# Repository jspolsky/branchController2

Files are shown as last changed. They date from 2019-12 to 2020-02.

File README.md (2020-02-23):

branchController
================

The Branch Controller is a small hardware board based on the [Teensy 3.2 development board](https://www.pjrc.com/store/teensy32.html) to allow it to control up to 8 separate pixel-addressible LED strips.

Although it can be used standalone to send its own patterns to the light strips, it really shines when connected, over ethernet, to a network. That allows you to generate the patterns on a computer (say, with a high powered graphics card) and send them to one or more Branch Controllers. In particular you can drive a lot more LEDs than any single controller can drive by using multiple Branch Controllers.

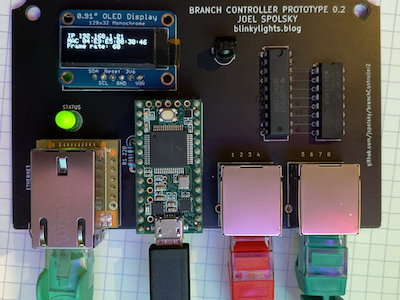
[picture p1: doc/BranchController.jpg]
Branch Controller


It is designed for WS2812b-style LED strips, with a single wire protocol. These are what Adafruit calls "NeoPixels".

Personally I like to use the WS2815 variant which runs on 12 volts and has a backup wire allowing any single pixel to fail. 

Branch Controller does *not* handle APA102c-type strips, which use a two wire protocol consisting of both the signal and a clock.

Features:

* Supports up to 4400 pixels (550 per strip) at a frame rate of 60 Hz, the theoretical limit of the protocol

* Ethernet control. Connects to an ethernet network to receive pixel data over TCP/IP. This allows you to use many branch controllers controlled from a single PC

* 128x32 OLED display for diagnostics and network configuration

* IR sensor allows you to use an IR remote control for basic controls

Basic Operation
---------------

By default branchController assumes you have 8 strips of 550 pixels each. You can operate a single branchController with a 44 button IR remote control like this one:

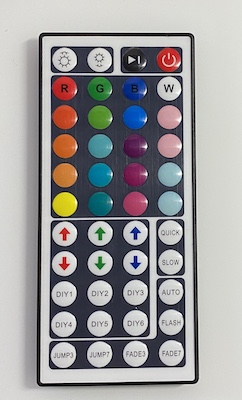
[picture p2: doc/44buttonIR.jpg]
44 button IR remote control


The brightness and color buttons work out of the box so you can use your branch controller to create basic solid colors. 

Use the On/Off button on the remote to turn off the LEDs. When you press OFF, any changes you have made to the state of the branchController is saved to EEPROM so that it will come back in the same state when you power up. *If you don't press off, the state is never saved*.

The DIY1-6 buttons are reserved for internal test patterns and chases. You can edit the code for these to provide something that is a good backup if your PC or network fails.

DIY1 shows a test pattern where the first pixel is brown on the first strip, the first two pixels are brown on the second strip, etc. This is useful for making sure you have the 8 strips hooked up in the right order.

Network Operation
-----------------

You can connect your branchController to a LAN using the built-in ethernet port and control it from any kind of computer that speaks TCP/IP.

When branchController starts up, it will look for a DHCP server and try to get an IP address and network configuration. If that works it will show you the IP address on the screen.

Every branch controller has a unique MAC address which will never change, so you can configure your DHCP server to always hand out the same IP address to the same branch controller, which makes it easier to sort out multiple branch controllers.

If you would like to use a static IP address:

* Start up the branch controller once using DHCP
* Connect to the web server running at the IP address that you see on the OLED display
* Check the "static IP" box and enter the IP address you want to use. Click submit
* Restart the branch controller. From now on it will use your static IP address.

Web-based Hardware Configuration
--------------------------------

If you don't like the default configuration, you can use a web browser to connect to your
branchController and modify some things:

* the maximum power that LEDs will be allowed to consume (in milliwatts). If the total power budget is exceeded, all LEDs will be dimmed equally.
* the RGB order in your LED strips (some strips expect RGB, others expect GRB). Use the "red", "green", and "blue" buttons to diagnose incorrect RGB order.
* the color correction you want applied to all output, as a six digit hex RGB value
* the color temperature you want applied to all output, as a six digit hex RGB value
* the overall brightness of the LEDs, on a scale from 0 (off) to 255 (full). This can
  also be adjusted with an IR remote
* whether to use a static IP address 

See http://fastled.io/docs/3.1/group___color_enums.html for options for color correction and 
color temperature.

Open Pixel Control
------------------

If branchController successfully gets on the Internet, it will listen for TCP connections on port 7890, where it will receive data sent to it using the Open Pixel Control format, documented [here](http://openpixelcontrol.org/). You can use Christopher Schardt's app [L.E.D. Lab](https://apps.apple.com/us/app/l-e-d-lab/id832042156) for iPhone or iPad to send cool animations -- all you need to do is set up the controller as if it were a FadeCandy controller.

We use TCP and not UDP for Open Pixel Control. The w5500 ethernet chip used in this design has a tiny buffer and will lose UDP packets if they are sent too fast. TCP solves this problem.

About the project
-----------------

This code was built using PlatformIO, an open source platform for embedded development which is a zillion times better than using the Arduino IDE. You will still need Teensyduino to flash the Teensy. For more about the research behind this project, follow my blog, [BlinkyLights](https://blinkylights.blog/).

Want to build one?
-------------------
* The gerber directory has gerber and drill files so you can order PCBs.
* This [BOM](https://octopart.com/bom-tool/tv6ZDeDl) lists the parts you need.
* The PCB is designed to be mounted in a Polycase SK-16-03 if you want a weatherproof enclosure

Next Up
-------

Recently implemented:
- [X] Static IP address
- [X] Faster brightness adjust

These features are planned REAL SOON NOW:
- [ ] Improve power limiting feature by showing stats on display for diagnosis
- [ ] "Count Pixels" mode
- [ ] Investigate temporal dithering - it's not really happening. 
- [ ] Internet cable disconnected / reconnected
- [ ] Better built-in (DIY1-6) displays maybe
- [ ] Support remote control Play/Pause button for internal DIY1-6 displays
- [ ] Either implement gamma correction or stop pretending

Ideas for future improvements:
- [ ] New hardware design with ESP32 and logic shifters to handle way more LEDs
- [ ] TouchDesigner support
- [ ] DMX/ArtNet bridge mode
- [ ] Multicast DNS (mDNS) and service discovery (DNS-SD)
      try https://github.com/TrippyLighting/EthernetBonjour

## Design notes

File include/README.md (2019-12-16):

Hey! I hate C++ objects. So I don't really use them that much. We use namespaces instead.

Each "module" defines one namespace and consists of a .h file and a .cpp file. The average module implements both setup() and void() which do the usual Arduino things.

Global constants (like pin assignments) go in BranchController.h. 
Specific settings to this module go in ModuleName.h.

ModuleName.h
---

```
// Description of the module is 
// in the .h file

#pragma once

namespace ModuleName {
    void setup(void);
    void loop(void); 
}

```

ModuleName.cpp
---

```
#include <Arduino.h>
#include <BranchController.h>
#include <ModuleName.h>

namespace ModuleName {

    void setup(void)
    {

    }

    void loop(void)
    {

    }

}
```

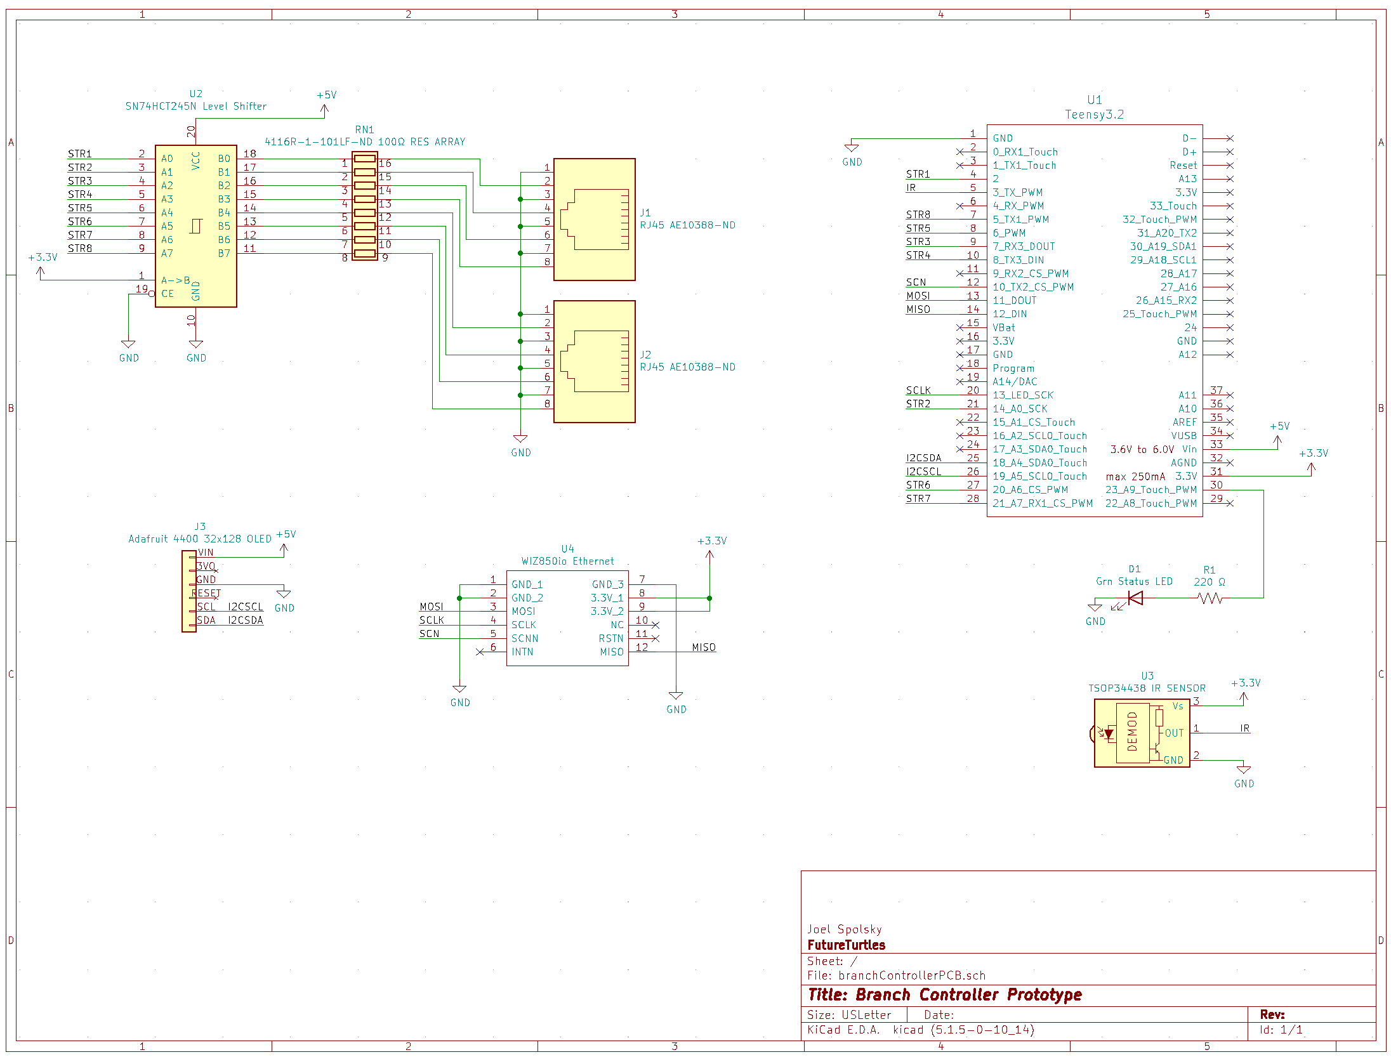
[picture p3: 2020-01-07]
kicad/BranchControllerSchematic.png

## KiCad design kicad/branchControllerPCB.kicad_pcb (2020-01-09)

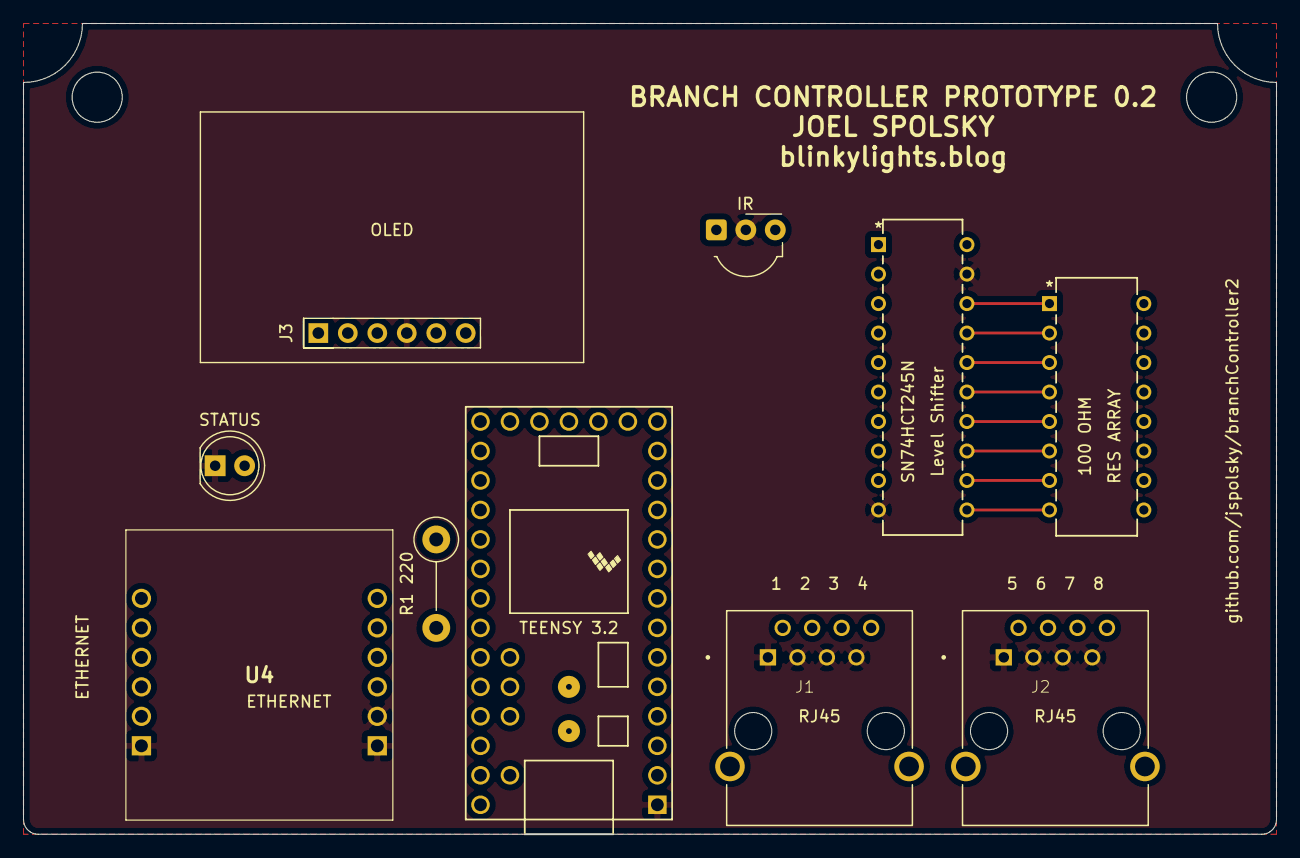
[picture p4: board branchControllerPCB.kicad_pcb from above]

Board: 4 copper layers, 107.9 x 69.9 mm, 10 parts (0 on the bottom side), 36 nets.

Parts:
100 OHM: RES ARRAY; 4116R-1-101LF
IR: TSOP34438 IR SENSOR; Vishay_MOLD-3Pin
J1, J2: RJ45 AE10388-ND; ASSMANN_A-2004-1-4-LP-N-R
J3: Adafruit 4400 32x128 OLED; AdaFruit4400LED
R1 220: 220 Ω; R_Axial_DIN0411_L9.9mm_D3.6mm_P7.62mm_Vertical
SN74HCT245N: Level Shifter; SN74HCT245N
STATUS: Grn Status LED; LED_D5.0mm
TEENSY 3.2: Teensy3.2; Teensy30_31_32_LC
U4: WIZ850io Ethernet; WIZ850io

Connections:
+3V3: IR.3, SN74HCT245N.1, TEENSY 3.2.31, U4.8, U4.9
+5V: J3.VIN, SN74HCT245N.20, TEENSY 3.2.33
/I2CSCL: J3.SCL, TEENSY 3.2.26
/I2CSDA: J3.SDA, TEENSY 3.2.25
/IR: IR.1, TEENSY 3.2.5
/MISO: TEENSY 3.2.14, U4.12
/MOSI: TEENSY 3.2.13, U4.3
/SCLK: TEENSY 3.2.20, U4.4
/SCN: TEENSY 3.2.12, U4.5
/STR1: SN74HCT245N.2, TEENSY 3.2.4
/STR2: SN74HCT245N.3, TEENSY 3.2.21
/STR3: SN74HCT245N.4, TEENSY 3.2.9
/STR4: SN74HCT245N.5, TEENSY 3.2.10
/STR5: SN74HCT245N.6, TEENSY 3.2.8
/STR6: SN74HCT245N.7, TEENSY 3.2.27
/STR7: SN74HCT245N.8, TEENSY 3.2.28
/STR8: SN74HCT245N.9, TEENSY 3.2.7
GND: IR.2, J1.1, J1.3, J1.5, J1.7, J2.1, J2.3, J2.5, J2.7, J3.GND, SN74HCT245N.10, SN74HCT245N.19, STATUS.1, TEENSY 3.2.1, U4.1, U4.2, U4.7
unnamed: R1 220.1, STATUS.2
unnamed: 100 OHM.16, J1.2
unnamed: 100 OHM.15, J1.4
unnamed: 100 OHM.14, J1.6
unnamed: 100 OHM.13, J1.8
unnamed: 100 OHM.12, J2.2
unnamed: 100 OHM.11, J2.4
unnamed: 100 OHM.10, J2.6
unnamed: 100 OHM.9, J2.8
unnamed: R1 220.2, TEENSY 3.2.30
unnamed: 100 OHM.1, SN74HCT245N.18
unnamed: 100 OHM.2, SN74HCT245N.17
unnamed: 100 OHM.3, SN74HCT245N.16
unnamed: 100 OHM.4, SN74HCT245N.15
unnamed: 100 OHM.5, SN74HCT245N.14
unnamed: 100 OHM.6, SN74HCT245N.13
unnamed: 100 OHM.7, SN74HCT245N.12
unnamed: 100 OHM.8, SN74HCT245N.11

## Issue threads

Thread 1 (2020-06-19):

How feasible might PoE be?

onpaws, 2020-06-19:
This is super interesting project, thanks for sharing publicly!

I'm a noob who recently setup my place with PoE-powered WAPs (802.3bt), and the simplicity of one wire has grown on me.
I see the Teensy's take power via USB. I was curious if you've seen microcontrollers that take, or could take, PoE. Is it a dumb idea? Curious your take.

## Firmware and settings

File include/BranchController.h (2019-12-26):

#pragma once

#define pinIRReceiver   3
#define pinEthernetCS   10
#define pinHeartbeat    23

#define MAX_LEDS_PER_STRIP 550
// Pin layouts for LEDs will be: 2,14,7,8,6,20,21,5

#define OPEN_PIXEL_PORT 7890

#define BRIGHTNESS 32

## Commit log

2019-12-16 distinctive heartbeat led shows our code is running
2019-12-17 Minor cleanups to debug printing code
2019-12-19 support for solid color buttons on remote control
2019-12-19 remember state on power off
2019-12-20 figured out how to get a Mac address from a Teensy
2019-12-21 turn off display when OFF button is pressed
2019-12-22 Started creating schematic in KiCad
    [branchControllerPCB.kicad_pcb, branchControllerPCB.sch]
2019-12-22 finished the schematics in kicad
    [branchControllerPCB.sch]
2019-12-22 finished designing prototype circuit board
    [branchControllerPCB.sch]
2019-12-23 tweaks and improvements to PCB
    [branchControllerPCB.kicad_pcb]
2019-12-23 final kicad
    [branchControllerPCB.kicad_pcb]
2019-12-24 brightness control, frame rate report
2019-12-25 frame rate calc
2020-01-02 BOM link
2020-01-03 fixed link to bom
2020-01-03 gerber files ... UNTESTED!
    [branchControllerPCB-B_Cu.gbr, branchControllerPCB-B_Mask.gbr, branchControllerPCB-B_Paste.gbr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]
2020-01-07 check the schematic in, in case it helps anyone
2020-01-09 Tweaked PCB dimensions
    No electrical changes
    [branchControllerPCB-B_Cu.gbr, branchControllerPCB-B_Mask.gbr, branchControllerPCB-B_Paste.gbr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]
2020-01-28 Wait 5s after last OPC msg before switching to default pattern

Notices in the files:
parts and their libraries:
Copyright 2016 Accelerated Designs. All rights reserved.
